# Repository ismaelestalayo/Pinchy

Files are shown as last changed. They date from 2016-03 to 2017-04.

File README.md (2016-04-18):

# Pinchy

<p align="center">
  
</p>

[Pinchy](http://bilbaodynamics.com/pinchy) is presented as the second iteration of our previous robot, [uBot](http://bilbaodynamics.com/tenacitas). It is an **educational** robot specifically made to be used as an ideal medium to start learning to program, know more about robotics and familiarize yourself with the basic electronic concepts.

### What's this?

Pinchy is an **open source** educational robot that can be printed using ordinary 3D printers. It's made up of a PCB, used as a shield with an Arduino Micro on top of it, the before mentioned chasis and some sensors to interact.

| **Unidades** 	| **Componente** 	|
|:---:	|:---:	|
| 2 	| Continuous Rotation Servos 	|
| 1 	| Ultrasound Sensor 	|
| 2 	| Line Follower Sensor 	|
| 1 	| RGB LED 	|
| 1 	| Buzzer 	|
| 1 	| Bluetooth Module 	|
| 1 	| Protoboard 	|
| 1 | 5x7 LED Array |
| 1 | Arduino Micro |

## I/O Ports

| **Pin** | **Function** |
|:---:|:---:|
| 0 | TX / BT Module |
| 1 | RX / BT Module |
| 2 | Buzzer |
| 3 | Free I/O / Pincer Servo |
| 4 | Optorreflector 1 |
| 5 | Servomotor 1 |
| 6 | Servomotor 2 |
| 7 | Trigger Ultrasound Sensor |
| 8 | Echo Ultrasound Sensor |
| 9 | Blue RGB LED |
| 10 | Red RGB LED |
| 11 | Green RGB LED |
| 12 | Optorreflector 2 |
| 13 | Free I/O |
| 14 | Push Switch |
| 15 | MAX7219 SCK |
| 16 | MAX7219 MOSI |
| 17 | MAX7219 SS |
| A0 | Free I/O |
| A1 | Free I/O |
| A2 | Free I/O |
| A3 | Free I/O |
| A4 | Free I/O |
| A5 | Free I/O |
| A6 | Free I/O |
| A7 | Free I/O |

## Files

### Chasis

The chasis that makes this robot more than a custom PCB with an Arduino is made with our 3D printers helping us to reduce the costs of assembling a fully functional educational robot. All the necessary files are [here](https://github.com/BilbaoDynamics/Pinchy/tree/master/Chasis).

<p align="center">
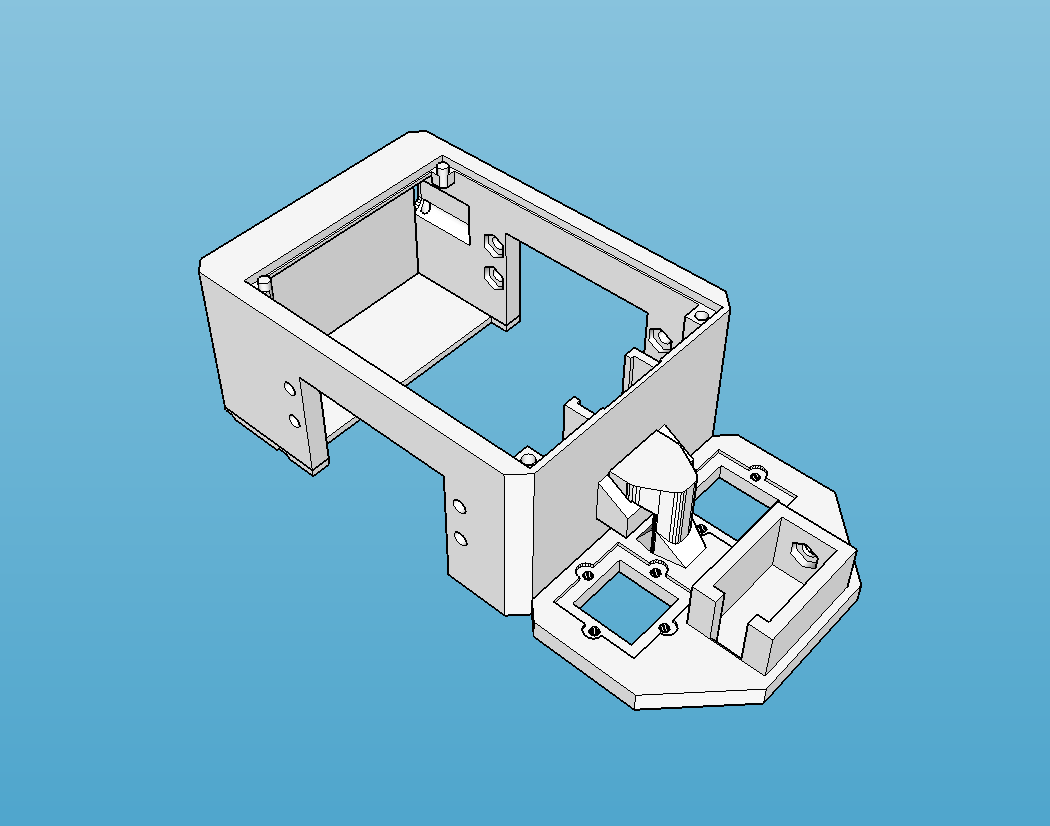
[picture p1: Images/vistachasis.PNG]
  
</p>

>
Pinchy's chasis without the circuitry
>

### Circuit and Board

<p align="center">
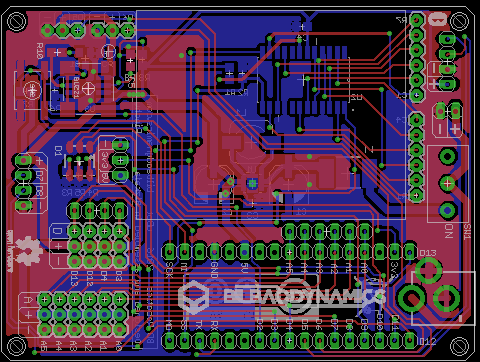
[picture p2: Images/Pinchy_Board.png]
  
</p>

>
Pinchy's main PCB
>

The circuitry that is needed is in the [Circuits](https://github.com/BilbaoDynamics/Pinchy/tree/master/Circuitos) folder, there you can find the schematics and the CAD files for the main PCB and for the custom-made optoreflectors.

## Contributing to this project

If you find a bug in the code or an issue in the circuit, we would like to know it so please follow the next steps so we are aware of it:

1. Fork this repository
2. Create your feature branch: `git checkout -b my-new-feature`
3. Commit your changes: `git commit -am "Hey Bilbao Dynamics, I've added something that you might like!"`
4. Push to the branch: `git push origin my-new-feature`
5. Submit a pull request and we might add it to the project! 😉

## License

GPL license or Creative Commons Attribution-ShareAlike (Copyleft)

<p align="center">
  
</p>

## Contact us

We are an active group of students that want to stay in touch if there are some issues or new things that you want to share with us. We are available on the following sites:

* [Twitter](https://twitter.com/BilbaoDynamics)
* [Facebook](https://www.facebook.com/BilbaoDynamics/)
* [Our website](https://www.bilbaodynamics.com)

>
Bilbao Dynamics @ 2016
>

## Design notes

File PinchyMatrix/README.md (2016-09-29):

PinchyMatrix
==========
PinchyMatrix is an [Arduino](http://arduino.cc) library for MAX7219 and MAX7221 Led display drivers.
The code may also work with the [Teensy (3.1)](https://www.pjrc.com/teensy/)

This library has been initially based on LedControl library.

Documentation
-------------
Documentation for the library is on the [Github Project Pages]

Download
--------
The lastest binary version of the Library is always available from the 
[PinchyMatrix Release Page]

Install
-------
The library can be installed using the [standard Arduino library install procedure](http://arduino.cc/en/Guide/Libraries)

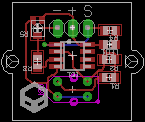
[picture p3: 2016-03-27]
Images/Pinchy_Optoreflector.png

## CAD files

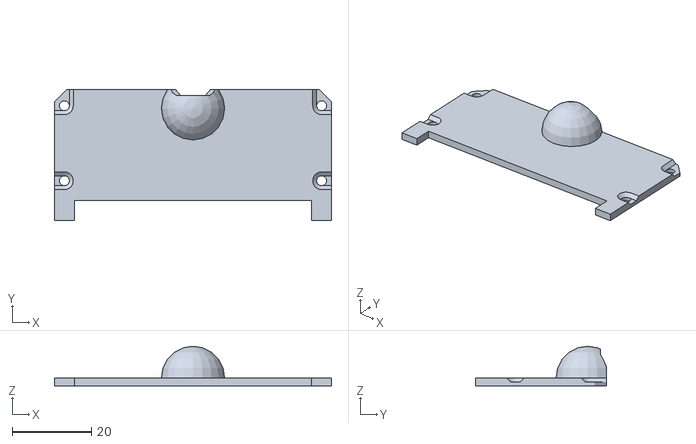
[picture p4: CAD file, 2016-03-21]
Chasis/inferior.stl
70.0 x 33.0 x 10.0

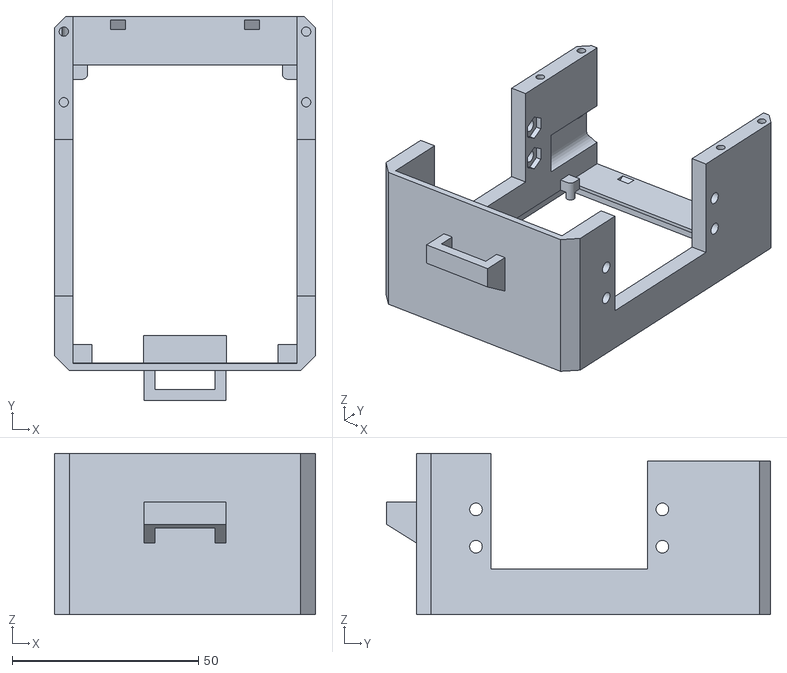
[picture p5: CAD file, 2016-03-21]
Chasis/Chasis.stl
70.0 x 103.0 x 43.2

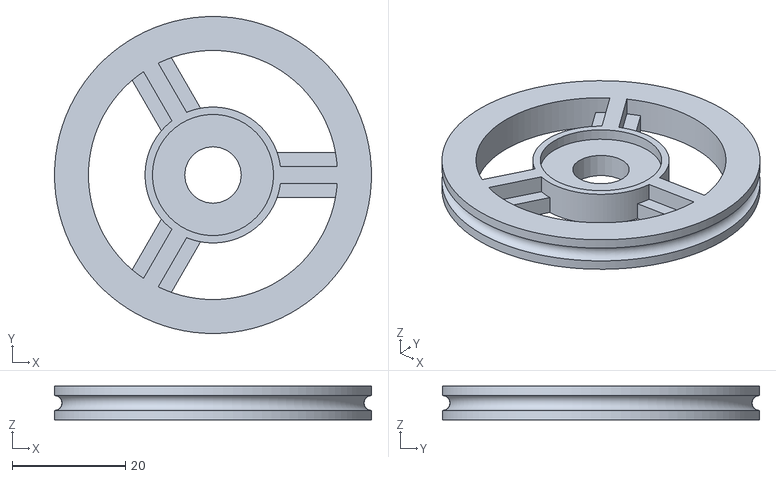
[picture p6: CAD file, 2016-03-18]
Chasis/Rueda.stl
56.0 x 56.0 x 6.00

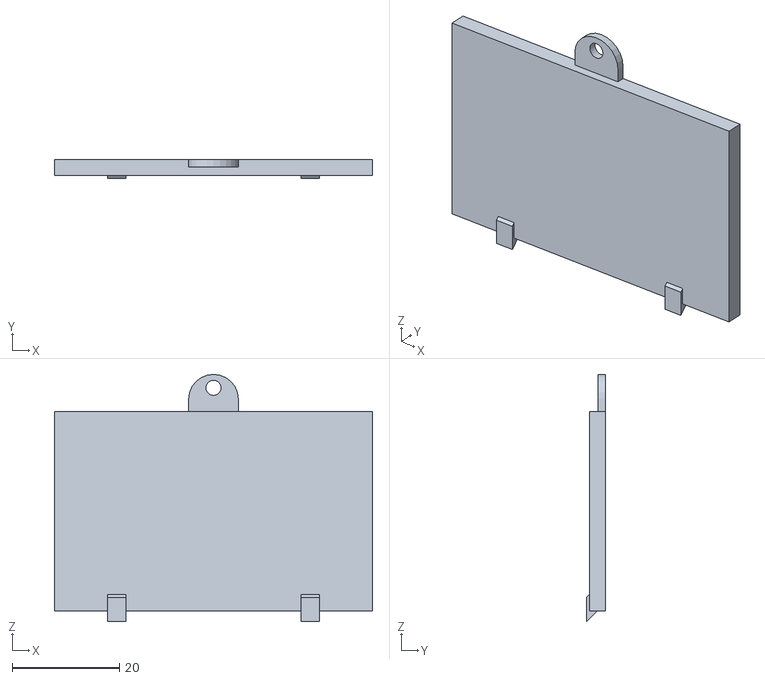
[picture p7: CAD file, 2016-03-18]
Chasis/Tapa_bateria.stl
59.2 x 3.50 x 46.0

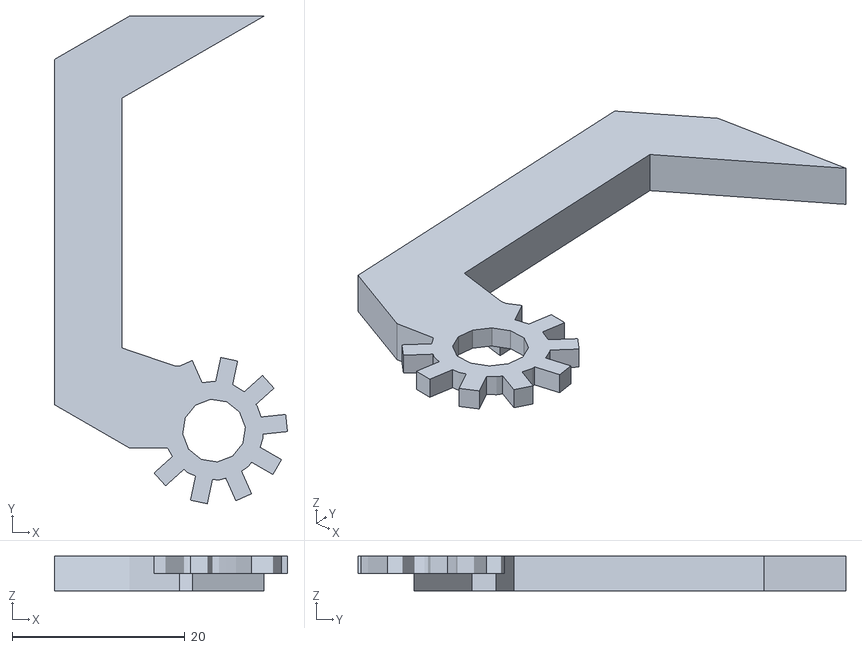
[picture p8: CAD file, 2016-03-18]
Chasis/Pinza_Derecha.stl
27.0 x 56.5 x 4.00

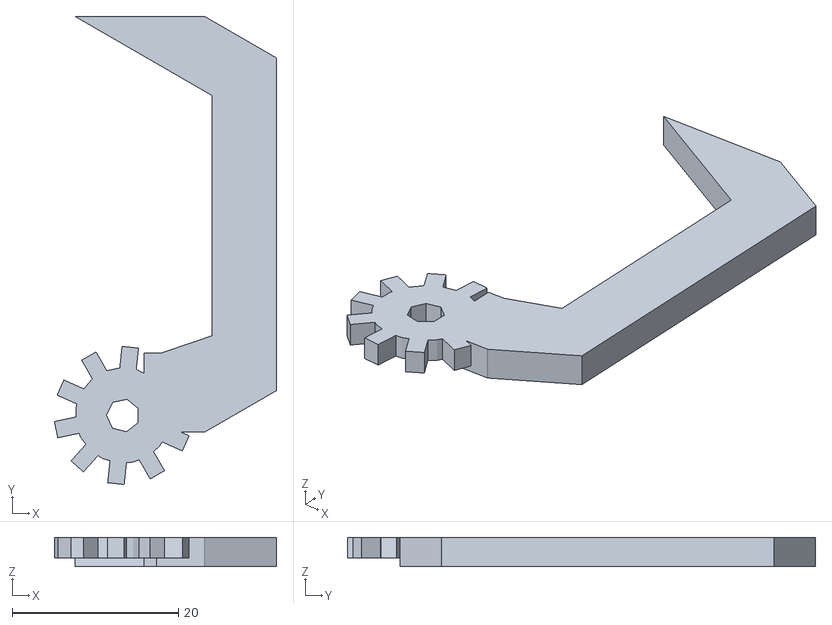
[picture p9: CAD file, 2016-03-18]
Chasis/Pinza_Izquierda.stl
26.8 x 56.3 x 3.50

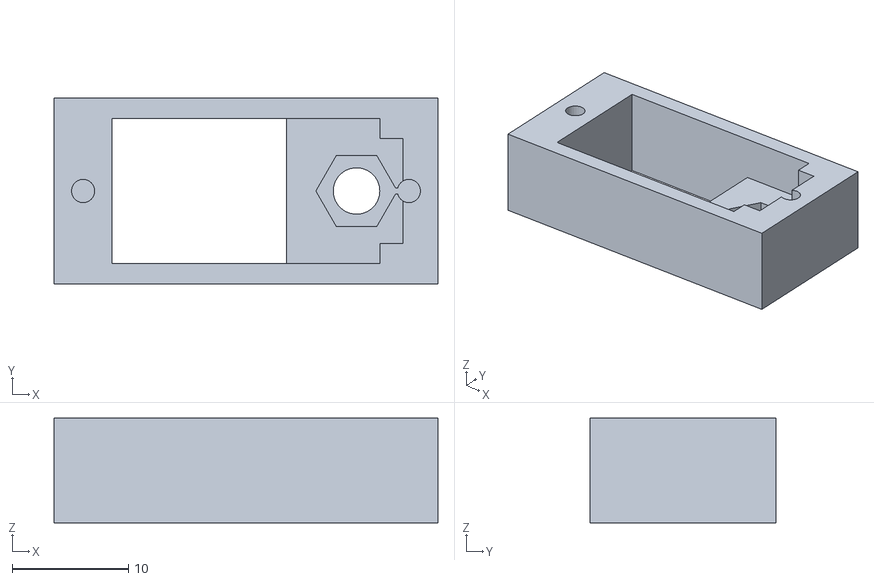
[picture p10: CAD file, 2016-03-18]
Chasis/Pinza_BloqueServo.stl
33.0 x 16.0 x 9.00

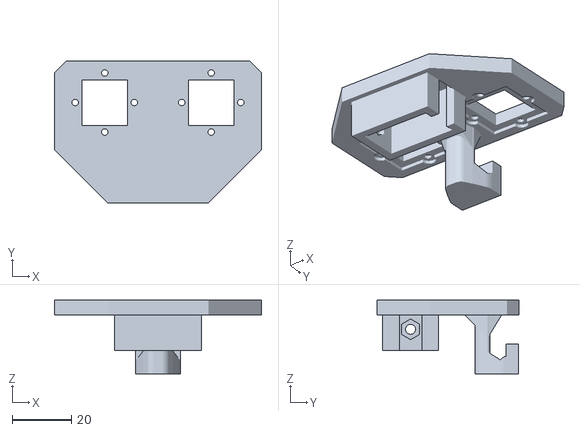
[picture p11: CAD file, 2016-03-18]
Chasis/Frontal.stl
70.0 x 48.0 x 25.0

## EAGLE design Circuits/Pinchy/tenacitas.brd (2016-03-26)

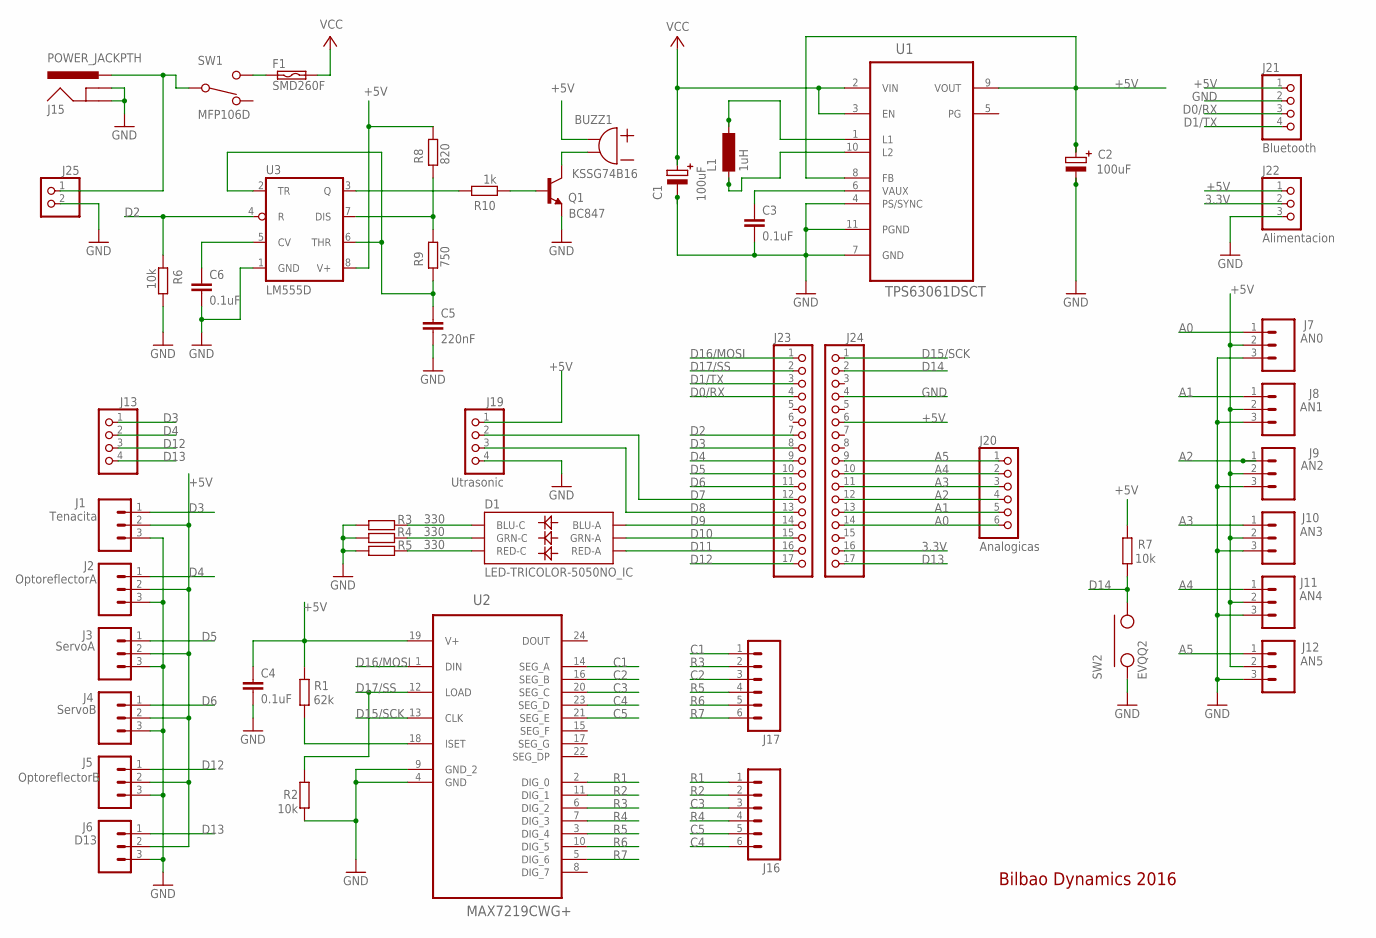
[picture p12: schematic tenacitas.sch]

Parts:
BUZZ1: KSSG74B16
C1, C2: 100uF; EDK107M016A9G
C3, C4, C6: 0.1uF; C0805
C5: 220nF; C0805
D1: LED-TRICOLOR-5050NO_IC; LED-TRICOLOR-5050
F1: SMD260F; SMD050F
J1: Tenacita; 1X03
J2: OptoreflectorA; 1X03
J3: ServoA; 1X03
J4: ServoB; 1X03
J5: OptoreflectorB; 1X03
J6: D13; 1X03
J7: AN0; 1X03
J8: AN1; 1X03
J9: AN2; 1X03
J10: AN3; 1X03
J11: AN4; 1X03
J12: AN5; 1X03
J13: PINHD-1X4; 1X04
J15: POWER_JACKPTH; POWER_JACK_PTH
J16, J17: M06SILK_FEMALE_PTH; 1X06
J19: Utrasonic; 1X04
J20: Analogicas; 1X06
J21: Bluetooth; 1X04
J22: Alimentacion; 1X03
J23, J24: PINHD-1X17; 1X17
J25: PINHD-1X2; 1X02
L1: 1uH; MCSDRH73B
Q1: BC847; SOT23
R1: 62k; R0805
R2, R6, R7: 10k; R0805
R3, R4, R5: 330; R0805
R8: 820; R0805
R9: 750; R0805
R10: 1k; R0805
SW1: MFP106D
SW2: EVQQ2; JAEGGER_MKII_EVQQ2
U1: TPS63061DSCT; SON50P300X300X80-11N
U2: MAX7219CWG+; SOIC127P1032X265-24N
U3: LM555D; SO08

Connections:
3.3V: J22.2, J24.16
+5V: BUZZ1.P$2 (2), BUZZ1.P$3 (2), C2.1, C4.1, J1.2, J2.2, J3.2, J4.2, J5.2, J6.2, J7.2, J8.2, J9.2, J10.2, J11.2, J12.2, J19.1, J21.1, J22.1, J24.6, R1.2, R7.2, R8.2, U1.8 (FB), U1.9 (VOUT), U2.19 (V+), U3.8 (V+)
A0: J7.1, J20.6, J24.14
A1: J8.1, J20.5, J24.13
A2: J9.1, J20.4, J24.12
A3: J10.1, J20.3, J24.11
A4: J11.1, J20.2, J24.10
A5: J12.1, J20.1, J24.9
C1: J17.1, U2.14 (SEG_A)
C2: J17.3, U2.16 (SEG_B)
C3: J16.3, U2.20 (SEG_C)
C4: J16.6, U2.23 (SEG_D)
C5: J16.5, U2.21 (SEG_E)
D0/RX: J21.3, J23.4
D1/TX: J21.4, J23.3
D2: J23.7, R6.1, U3.4 (R)
D3: J1.1, J13.1, J23.8
D4: J2.1, J13.2, J23.9
D5: J3.1, J23.10
D6: J4.1, J23.11
D7: J19.2, J23.12
D8: J19.3, J23.13
D9: D1.3 (BLU-A), J23.14
D10: D1.1 (GRN-A), J23.15
D11: D1.2 (RED-A), J23.16
D12: J5.1, J13.3, J23.17
D13: J6.1, J13.4, J24.17
D14: J24.2, R7.1, SW2.P$1, SW2.P$4
D15/SCK: J24.1, U2.13 (CLK)
D16/MOSI: J23.1, U2.1 (DIN)
D17/SS: J23.2, R2.2, U2.12 (LOAD)
GND: C1.2, C2.2, C3.2, C4.2, C5.2, C6.2, J1.3, J2.3, J3.3, J4.3, J5.3, J6.3, J7.3, J8.3, J9.3, J10.3, J11.3, J12.3, J15.GND, J15.GNDBREAK, J19.4, J21.2, J22.3, J24.4, J25.2, Q1.2 (E), R2.1, R3.1, R4.1, R5.1, R6.2, SW2.P$2, SW2.P$3, U1.4 (PS/SYNC), U1.7 (GND), U1.11 (PGND), U2.4 (GND), U2.9 (GND_2), U3.1 (GND)
unnamed: R8.1, R9.2, U3.7 (DIS)
unnamed: R10.2, U3.3 (Q)
unnamed: D1.4 (BLU-C), R3.2
unnamed: D1.6 (GRN-C), R4.2
unnamed: C3.1, U1.6 (VAUX)
unnamed: D1.5 (RED-C), R5.2
unnamed: L1.2, U1.1 (L1)
unnamed: L1.1, U1.10 (L2)
unnamed: BUZZ1.P$1 (1), BUZZ1.P$4 (1), Q1.3 (C)
unnamed: C5.1, R9.1, U3.2 (TR), U3.6 (THR)
unnamed: F1.1, SW1.2
unnamed: C6.1, U3.5 (CV)
unnamed: Q1.1 (B), R10.1
unnamed: R1.1, U2.18 (ISET)
unnamed: J15.PWR, J25.1, SW1.COM
R1: J16.1, U2.2 (DIG_0)
R2: J16.2, U2.11 (DIG_1)
R3: J17.2, U2.6 (DIG_2)
R4: J16.4, U2.7 (DIG_3)
R5: J17.4, U2.3 (DIG_4)
R6: J17.5, U2.10 (DIG_5)
R7: J17.6, U2.5 (DIG_6)
VCC: C1.1, F1.2, U1.2 (VIN), U1.3 (EN)

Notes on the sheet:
Bilbao Dynamics 2016

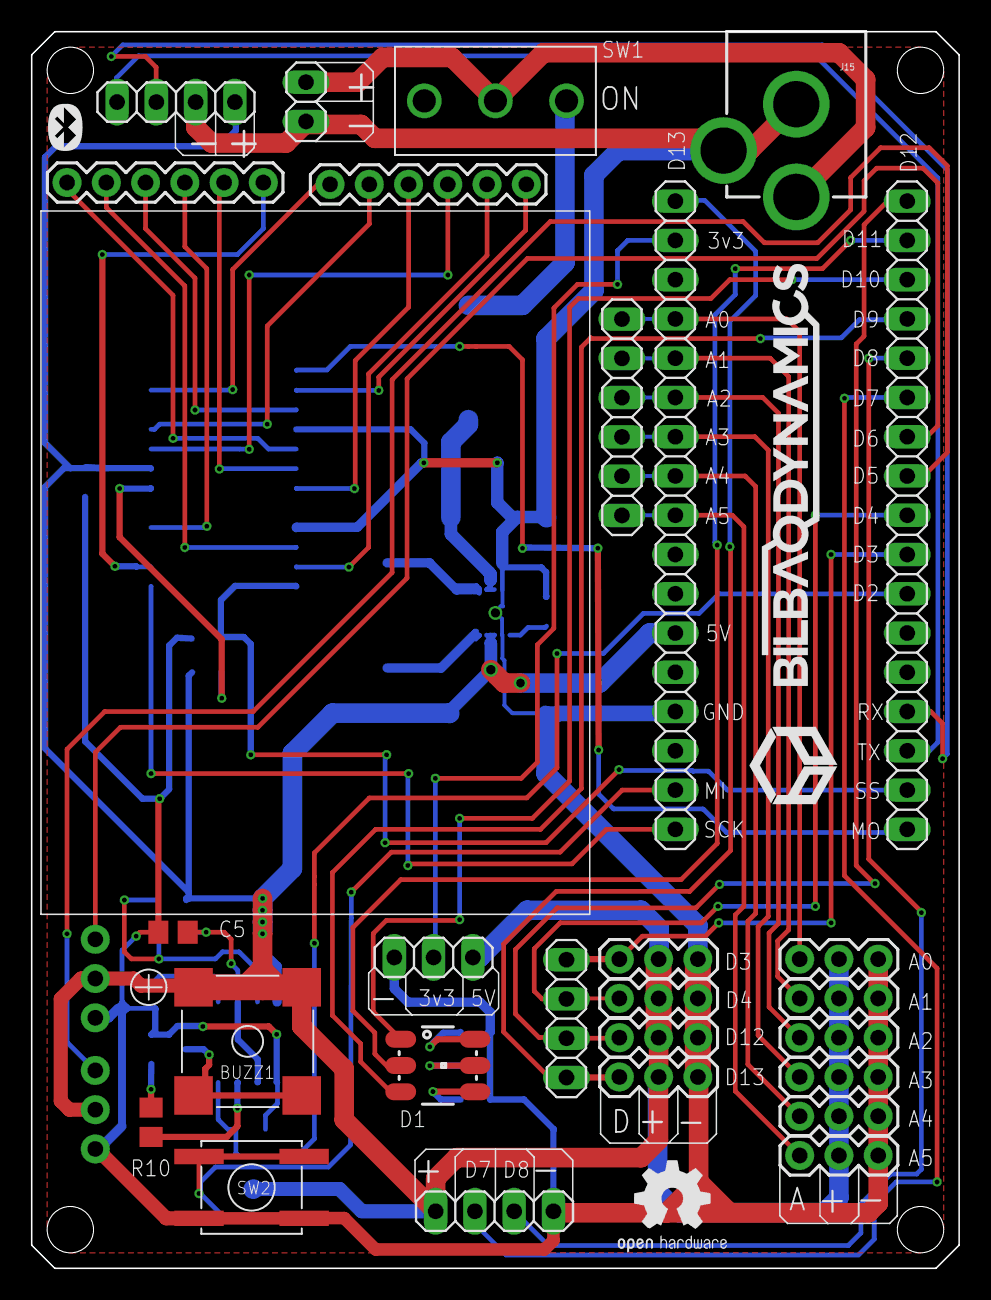
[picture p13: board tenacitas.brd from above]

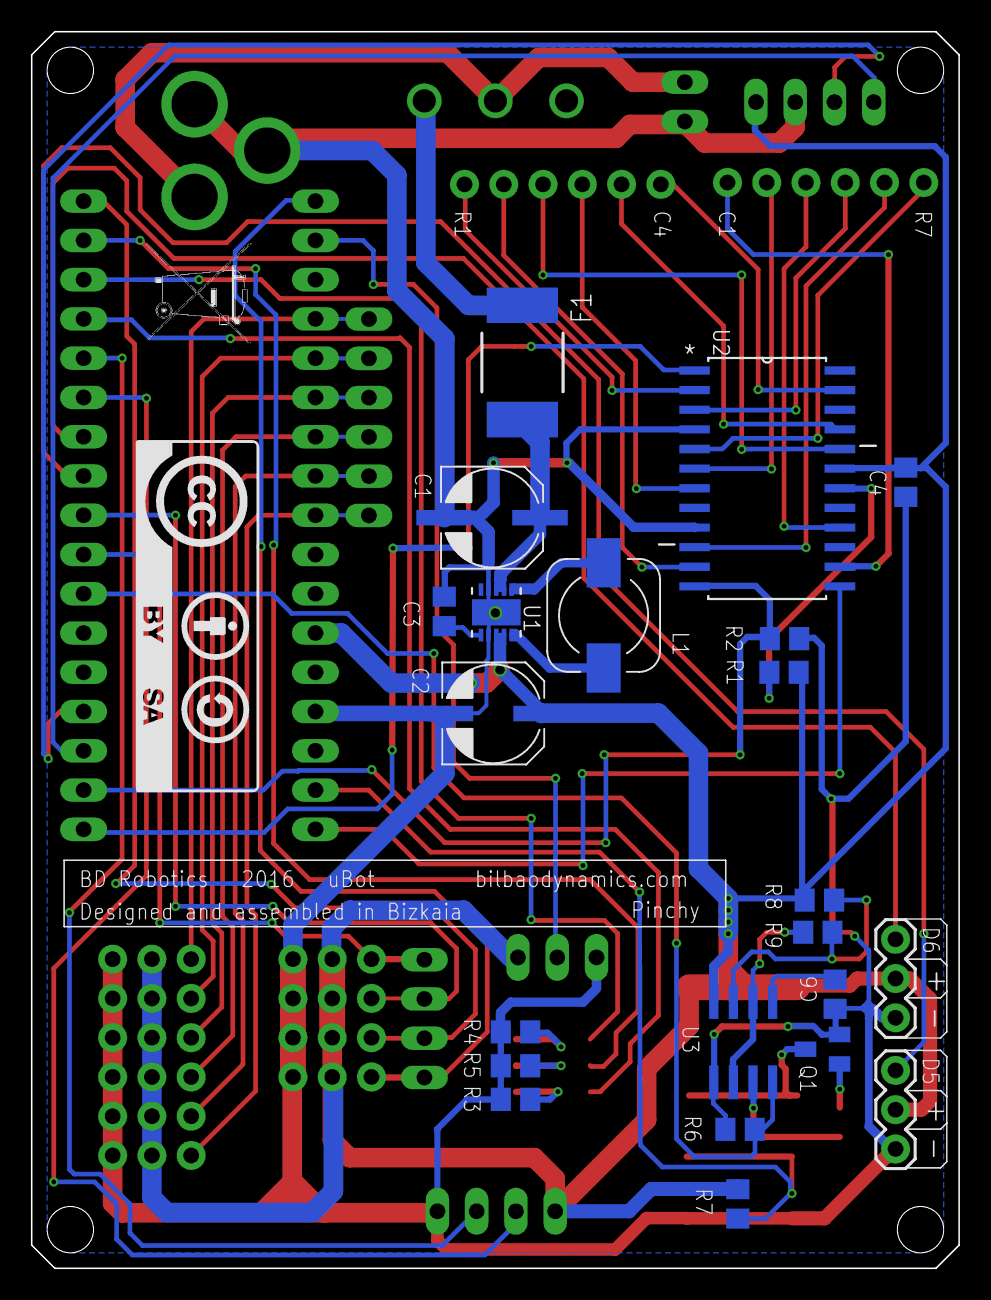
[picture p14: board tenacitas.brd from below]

Board: 2 copper layers, 60.0 x 80.0 mm, 49 parts (22 on the bottom side), 55 nets.

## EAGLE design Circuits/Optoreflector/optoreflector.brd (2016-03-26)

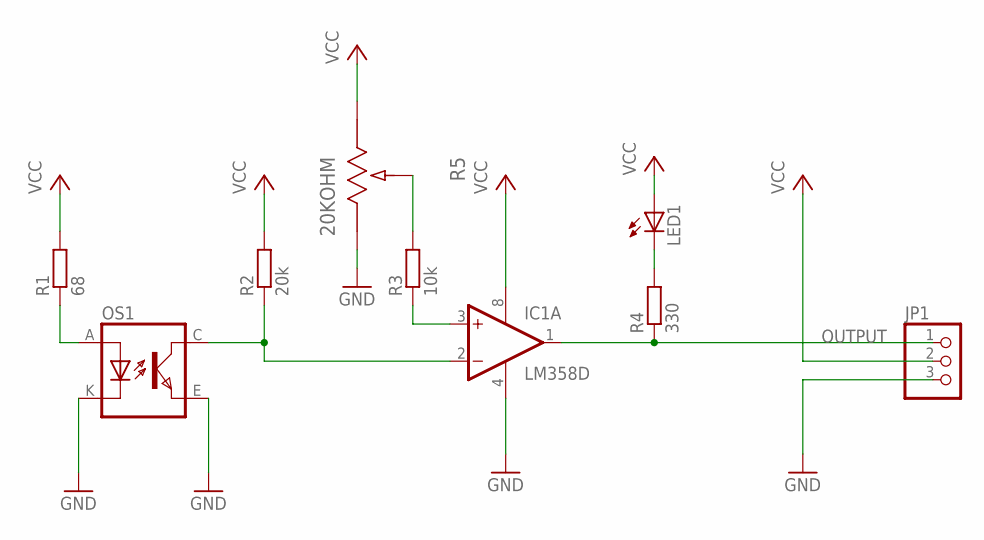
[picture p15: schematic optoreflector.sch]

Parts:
IC1: LM358D; SO08
JP1: PINHD-1X3; 1X03
LED1: LEDCHIP-LED0805; CHIP-LED0805
OS1: TCRT5000
R1: 68; R0805
R2: 20k; R0805
R3: 10k; R0805
R4: 330; R0805
R5: 20KOHM; POT_EVM2W

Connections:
GND: IC1.4 (V-), JP1.3, OS1.E (EMITTER), OS1.K (CATHODE), R5.3
unnamed: LED1.C, R4.2
unnamed: OS1.A (ANODE), R1.1
unnamed: IC1.2 (-IN), OS1.C (COLLECTOR), R2.1
unnamed: R3.2, R5.2
unnamed: IC1.3 (+IN), R3.1
OUTPUT: IC1.1 (OUT), JP1.1, R4.1
VCC: IC1.8 (V+), JP1.2, LED1.A, R1.2, R2.2, R5.1

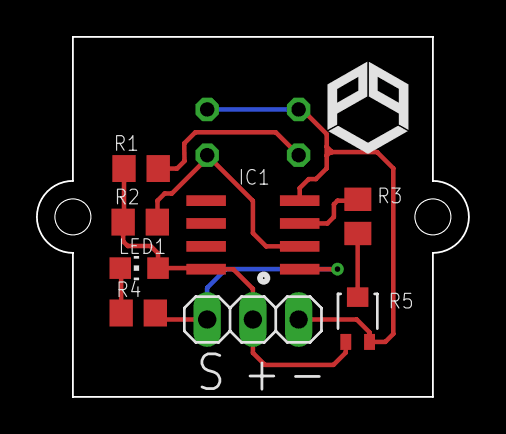
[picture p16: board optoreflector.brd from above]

Board: 2 copper layers, 24.0 x 20.0 mm, 9 parts (1 on the bottom side), 8 nets.

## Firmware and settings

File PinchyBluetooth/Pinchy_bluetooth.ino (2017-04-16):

//AT+NAME____
#include <Servo.h>

Servo servo1, servo2;

void setup() {
  Serial.begin(9600);
  Serial1.begin(9600);

  pinMode( 2, OUTPUT);    //BUZZER
  pinMode( 9, OUTPUT);    //BLUE
  pinMode(10, OUTPUT);    //RED
  pinMode(11, OUTPUT);    //GREEN

  servo1.attach(5);
  servo2.attach(6);
  servo1.write(90);
  servo2.write(90);
}

void loop() {
  while (Serial1.available()) {
    char c = Serial1.read();
    Serial.print(c);
    commandHandler(c); 
    }
  
  while (Serial.available()) {
    Serial1.write( Serial.read());
    }
}

//************************************************
void adelante() {
  servo1.write(0);
  servo2.write(180);
}
void atras() {
  servo1.write(0);
  servo2.write(180);
}
void derecha() {
  servo1.write(0);
  servo2.write(90);
}
void izquierda() {
  servo1.write(90);
  servo2.write(180);
}
void parar() {
  servo1.write(90);
  servo2.write(90);
}

//************************************************
void commandHandler(char c){
  switch (c) {
    case 'U':
      adelante();
      break;
    case 'D':
      atras();
      break;
    case 'L':
      izquierda();
      break;
    case 'R':
      derecha();
      break;
    case 'S':
      parar();
      break;

    case 'r':
      digitalWrite(10, !digitalRead(10) );
      break;
    case 'g':
      digitalWrite(11, !digitalRead(11) );
      break;
    case 'b':
      digitalWrite( 9, !digitalRead( 9) );
      break;
    
    case '1':
      break;
    case '2':
      digitalWrite(2, !digitalRead(2) );
      break;
  }
}

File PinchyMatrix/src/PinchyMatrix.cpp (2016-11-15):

/*
 *    PinchyMatrix.cpp - A library for controling Leds with a MAX7219/MAX7221
 *    This library has been designed for Pinchy, our robot, but you can use it
 *    with a display.
 *    Copyright (c) 2007 Eberhard Fahle [based on LedControl.cpp]
 *
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
 *    This permission notice shall be included in all copies or
 *    substantial portions of the Software.
 *
 *    THE SOFTWARE IS PROVIDED "AS IS", WITHOUT WARRANTY OF ANY KIND,
 *    EXPRESS OR IMPLIED, INCLUDING BUT NOT LIMITED TO THE WARRANTIES
 *    OF MERCHANTABILITY, FITNESS FOR A PARTICULAR PURPOSE AND
 *    NONINFRINGEMENT. IN NO EVENT SHALL THE AUTHORS OR COPYRIGHT
 *    HOLDERS BE LIABLE FOR ANY CLAIM, DAMAGES OR OTHER LIABILITY,
 *    WHETHER IN AN ACTION OF CONTRACT, TORT OR OTHERWISE, ARISING
 *    FROM, OUT OF OR IN CONNECTION WITH THE SOFTWARE OR THE USE OR
 *    OTHER DEALINGS IN THE SOFTWARE.
 */


#include "PinchyMatrix.h"

//the opcodes for the MAX7221 and MAX7219
#define OP_NOOP   0
#define OP_DIGIT0 1
#define OP_DIGIT1 2
#define OP_DIGIT2 3
#define OP_DIGIT3 4
#define OP_DIGIT4 5
#define OP_DIGIT5 6
#define OP_DIGIT6 7
#define OP_DIGIT7 8
#define OP_DECODEMODE  9
#define OP_INTENSITY   10
#define OP_SCANLIMIT   11
#define OP_SHUTDOWN    12
#define OP_DISPLAYTEST 15


PinchyMatrix::PinchyMatrix(int dataPin, int clkPin, int csPin) {

    SPI_MOSI=dataPin;
    SPI_CLK=clkPin;
    SPI_CS=csPin;
    pinMode(SPI_MOSI,OUTPUT);
    pinMode(SPI_CLK,OUTPUT);
    pinMode(SPI_CS,OUTPUT);
    digitalWrite(SPI_CS,HIGH);
    SPI_MOSI=dataPin;
    for(int i=0;i<64;i++)
        status[i]=0x00;
    spiTransfer(OP_DISPLAYTEST,0);
    //scanlimit is set to max on startup
    setScanLimit(7);
    //decode is done in source
    spiTransfer(OP_DECODEMODE,0);
    clearDisplay();
    //we go into shutdown-mode on startup
    shutdown(true);
}

void PinchyMatrix::shutdown(bool b) {
    if(b)
        spiTransfer(OP_SHUTDOWN,0);
    else
        spiTransfer(OP_SHUTDOWN,1);
}

void PinchyMatrix::setScanLimit(int limit) {
    if(limit>=0 && limit<8)
        spiTransfer(OP_SCANLIMIT,limit);
}

void PinchyMatrix::setIntensity(int intensity) {
    if(intensity>=0 && intensity<16)
        spiTransfer(OP_INTENSITY,intensity);
}

void PinchyMatrix::clearDisplay() {
    for(int i=0;i<8;i++) {
        status[i]=0;
        spiTransfer(i+1,status[i]);
    }
}

void PinchyMatrix::setLed(int row, int col, boolean state) {
    byte val=0x00;
    col++;
    row++;
    if(row<1 || row>5 || col<1 || col>7)
        return;
    val=B10000000 >> row;
    if(state)
        status[col]=status[col]|val;
    else {
        val=~val;
        status[col]=status[col]&val;
    }
    spiTransfer(col,status[col]);
}

void PinchyMatrix::setCol(int col, byte value) {
    if(col<0 || col>7)
        return;
    status[col]=value*4;
    spiTransfer(col+1,status[col]);
}

void PinchyMatrix::setRow(int row, byte value) {
    byte val;
    value*=2;
    if(row<0 || row>4)
        return;
    for(int col=0;col<8;col++) {
        val=value >> (7-col);
        val=val & 0x01;
        setLed(row,col,val);
    }
}


void PinchyMatrix::spiTransfer(volatile byte opcode, volatile byte data) {
    #define MAXBYTES 2

    for(int i=0;i<MAXBYTES;i++)
        spidata[i]=(byte)0;
    //put our device data into the array
    spidata[1]=opcode;
    spidata[0]=data;
    //enable the line
    digitalWrite(SPI_CS,LOW);
    //Now shift out the data
    for(int i=MAXBYTES;i>0;i--)
        shiftOut(SPI_MOSI,SPI_CLK,MSBFIRST,spidata[i-1]);
    //latch the data onto the display
    digitalWrite(SPI_CS,HIGH);
}

void PinchyMatrix::setMatrixByCols(byte tmp[7])
{
    for(int i=0; i<7; i++)
	spiTransfer(i+1,tmp[i]*4);
}

void PinchyMatrix::setMatrixByRows(byte tmp[5])
{
    for(int i=0; i<5; i++)
    {
	f[i]=tmp[i];
        setRow(i,tmp[i]);
    }
}

void PinchyMatrix::setMatrix()
{
    for(int i=0; i<5; i++)
        setRow(i,f[i]);
}

void PinchyMatrix::left()
{
  for (int i = 0; i<5; i++)
  {
      f[i]*=2;

    if(f[i]>127)
      f[i]-=127;
  }
  setMatrix();
}

void PinchyMatrix::right()
{
  for(int i=0; i<5; i++)
  {
    if(f[i]%2 == 1)
      f[i]+=127;
    f[i]/=2;

  }
  setMatrix();
}

void PinchyMatrix::up()
{
  byte tmp = f[4];
  for (int i=4; i>0; i--)
    f[i]=f[i-1];
  f[0] = tmp;
  setMatrix();
}

void PinchyMatrix::down()
{
  byte tmp = f[0];
  for(int i=0; i<4; i++)
    f[i] = f[i+1];
  f[4] = tmp;
  setMatrix();
}

void PinchyMatrix::number(int num) //numero entre 0 y 99
{
  byte decena = num/10;
  byte unidad = num-(10*decena);
  byte tabla[5][10] = {{7,1,7,7,1,7,7,1,7,7}, //f(0)
                       {5,1,4,1,1,1,5,1,5,1}, //f(1)
                       {5,1,7,3,7,7,7,1,7,7}, //f(2)
                       {5,1,1,1,5,4,4,1,5,5}, //f(3)
                       {7,3,7,7,5,7,7,7,7,7}};//f(4)
                      //0,1,2,3,4,5,6,7,8,9

  for(int i=0; i<5; i++)
  {
    f[i] = (tabla[i][unidad])+(16*tabla[i][decena]);
  }
  setMatrix();
}
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

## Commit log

2016-03-18 Añadida información al README.md y añadidos los diseños en 3D necesarios para el robot
    [Chasis v0.1.stl, Chasis+base.stl, Chasis_tapa_abajo.stl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]
2016-03-19 Corrección de errores
2016-03-21 Añadida imagen con todos los componentes del chasis y nuevos diseños
    [Chasis.stl, inferior.stl]
2016-03-22 Modificado error en los pines del LED RGB
2016-03-26 Incluidos los esquemáticos para Pinchy y el optoreflector
    [optoreflector.brd, optoreflector.sch, tenacitas.brd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]
2016-03-27 File translated to english 🇬🇧
2016-03-27 Added two images of the PCBs
2016-03-27 File translated to english 🇬🇧
2016-03-27 Updated Pinchy's PCB image
2016-04-18 Added circuits folder
    [optoreflector.brd, optoreflector.sch, tenacitas.brd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]
2016-09-29 Añadir librería matriz
    Librería para la matriz de Pinchy facilitando su programación.

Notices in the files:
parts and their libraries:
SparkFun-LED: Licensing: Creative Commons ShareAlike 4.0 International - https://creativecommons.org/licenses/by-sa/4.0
